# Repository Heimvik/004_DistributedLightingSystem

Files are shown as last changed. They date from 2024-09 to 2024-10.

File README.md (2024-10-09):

# Distributed LED System
## Overview
The Distributed LED System is a networked lighting project using ESP32 microcontrollers and individually addressable RGB LED strips. The system consists of a master node that processes signals and multiple slave nodes, each controlling a 1-meter LED strip. The system supports various lighting modes, including synchronization with music and spatial sound effects. When finished with the circuits to the second revision, the firmware for it will be developed in embedded C. Future progress will appear here shortly.

## Features

- **Centralized Control**: Master node coordinates LED patterns across all slave nodes.
- **Dynamic Lighting Modes**:
  - Static Colors
  - Dynamic Patterns
  - Music Synchronization
  - Spatial Sound Effects
- **Real-time Communication**: Efficiently communicates between master and slave nodes using MQTT/WebSockets.
- **User Interface**: Web-based or mobile app interface for control and configuration.

Status as of 09.10: Awaiting programmer for ESP32-WROOM32E, continuing prototyping with rpi.

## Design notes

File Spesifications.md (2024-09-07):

# Distributed LED System Specifications

## System Overview

The distributed LED system consists of several nodes, each controlling a 1-meter long LED strip. All nodes communicate with a central master node responsible for signal processing and coordinating the display patterns across all connected nodes. The system will support various lighting modes, including synchronization with music and spatial sound effects.

## System Components

- **Master Node**: Central processing unit responsible for signal processing, data transmission, and coordination of LED patterns across all slave nodes.
- **Slave Nodes**: Each node controls a 1-meter long LED strip and receives display instructions from the master node.
- **LED Strip**: Each LED strip is 1 meter long and consists of individually addressable RGB LEDs.

## Requirements

### 1. LED Strip Specifications

- **Number of LEDs per Strip**: 60 LEDs per meter (common specification for high-density strips).
- **Total Number of LEDs per Node**: 60 LEDs.

### 2. Power Consumption

- **Power Consumption per LED**: Approximately 0.24 watts (at full brightness, white).
- **Total Power Consumption per Node (White Standby)**: 
  - `60 LEDs x 0.24 watts/LED = 14.4 watts`.
  - Include an additional 10% margin for power supply inefficiencies and other components.
  - **Total Power Consumption per Node**: ~15.8 watts.

### 3. Communication Protocol

- **Master to Slave Communication**: Use a reliable communication protocol such as MQTT, HTTP, or a custom UDP/TCP protocol depending on latency and bandwidth requirements.
- **Data Transmission Rate**: Ensure data transmission supports real-time updates with minimal latency.

### 4. Lighting Modes

1. **Static Colors**: Fixed colors set by the master node.
2. **Dynamic Patterns**: Predefined or custom patterns such as waves, color shifts, and fades.
3. **Music Synchronization**:
   - **Beat Detection**: LEDs synchronize with the beats of the music.
   - **Frequency Bands**: Different frequency bands can control different LED segments or effects.
4. **Spatial Sound Effects**:
   - **Directionality**: LEDs placemnt in the room respond to distribution of sound between the channels.
   - **Sound Mapping**: Visual representation of sound sources or sound movement across the LED strips.

### 5. System Integration

- **Node Initialization**: Each node should be able to initialize and configure itself upon startup.
- **Scalability**: More nodes needs to be able to be added with no/minimum effort.

### 6. User Interface

- **Control Software**: Develop a user-friendly interface for controlling and configuring the system, including setting lighting modes and creating patterns.
- **Remote Access**: Provide options for remote control and monitoring of the system via a web interface or mobile app.

### 7. Power Supply

- **Power Supply Requirements**: Ensure each node has a stable and sufficient power supply.
- **Safety**: Include protection against overcurrent, short circuits, and overheating.

### 8. Environmental Considerations

- **Temperature Range**: Ensure the system operates reliably within the expected temperature range.
- **Humidity**: Consider humidity and potential exposure to moisture, especially for non-indoor installations.

### 9. Documentation

- **System Documentation**: Provide comprehensive documentation for setup, configuration, and troubleshooting.
- **API Documentation**: Document any APIs or communication protocols used for integration and control.

### 10. Testing and Validation

- **Functional Testing**: Validate all features and modes to ensure proper functionality.
- **Performance Testing**: Test the system's performance under various loads and conditions to ensure stability and responsiveness.

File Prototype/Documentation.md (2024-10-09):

# DSP prototype

## Server credentails
For the dsp server, the following credentials are used:
- username: heimvik
- ip: 192.168.0.134
Password is known.

## Requirements
The following is done in the setup.sh.
1. Running the requirements.

2.
. Configure curl
```cmd
curl --proto '=https' --tlsv1.2 -sSf https://sh.rustup.rs | sh
source $HOME/.cargo/env
```

3. First do:
```cmd
sudo apt update
sudo apt install build-essential libasound2-dev
git clone https://github.com/librespot-org/librespot.git
cd librespot
cargo build --release
./target/release/librespot --name "PLserver"
```
for the spotify librespot client.

4. Then install looback device:
```cmd
sudo apt install pulseaudio pavucontrol
```

5. Then install pyaudio to capture theaudio data from the virtual device:
```cmd
sudo apt install python3-pyaudio
pip3 install pyaudio
```

6. For doing real-time fft, we utilize the GPU and theGPU_FFT library on the pi.
```cmd
cd /opt/vc/src/hello_pi/hello_fft
make
sudo mknod char_dev c 100 0
```

7. Matplotlib and numpy for plotting and debugging the dsp:
```cmd
sudo apt install python3-matplotlib python3-numpy
```

8. Then set up the virtual loopback device:
```cmd
pactl load-module module-null-sink sink_name=loopback
pactl load-module module-loopback sink=loopback
```

That should be all the requirements.

Make sure the GUI is turned off, improving performance. Done by:
```cmd
sudo systemctl set-default multi-user.target
```

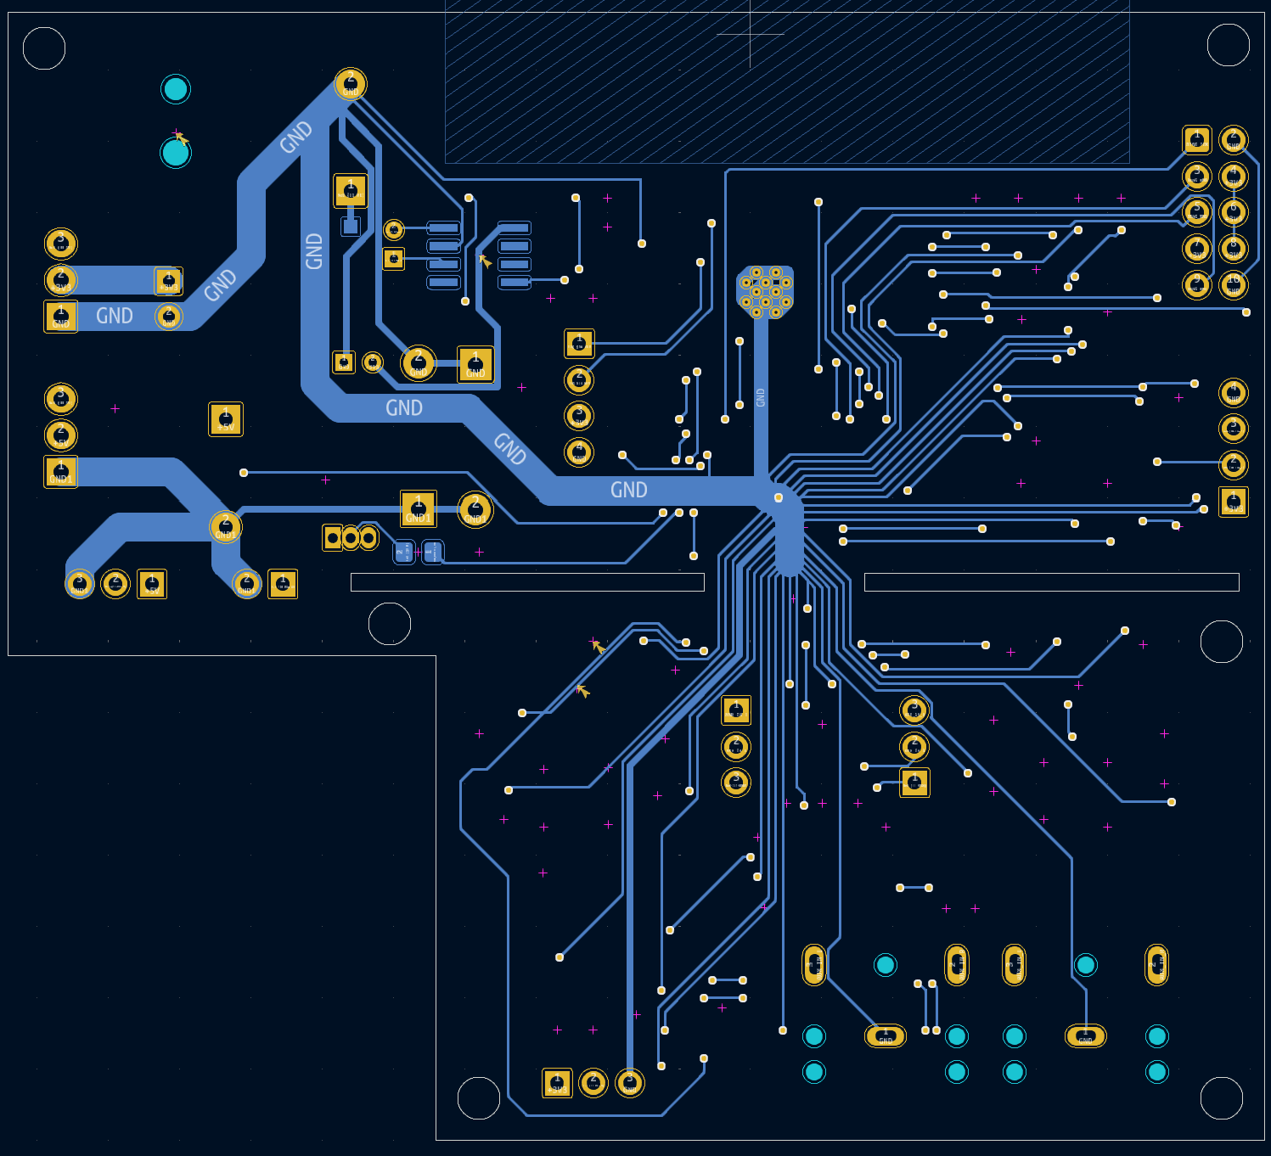
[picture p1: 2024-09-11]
Documentation/LAYER_B_CU.png

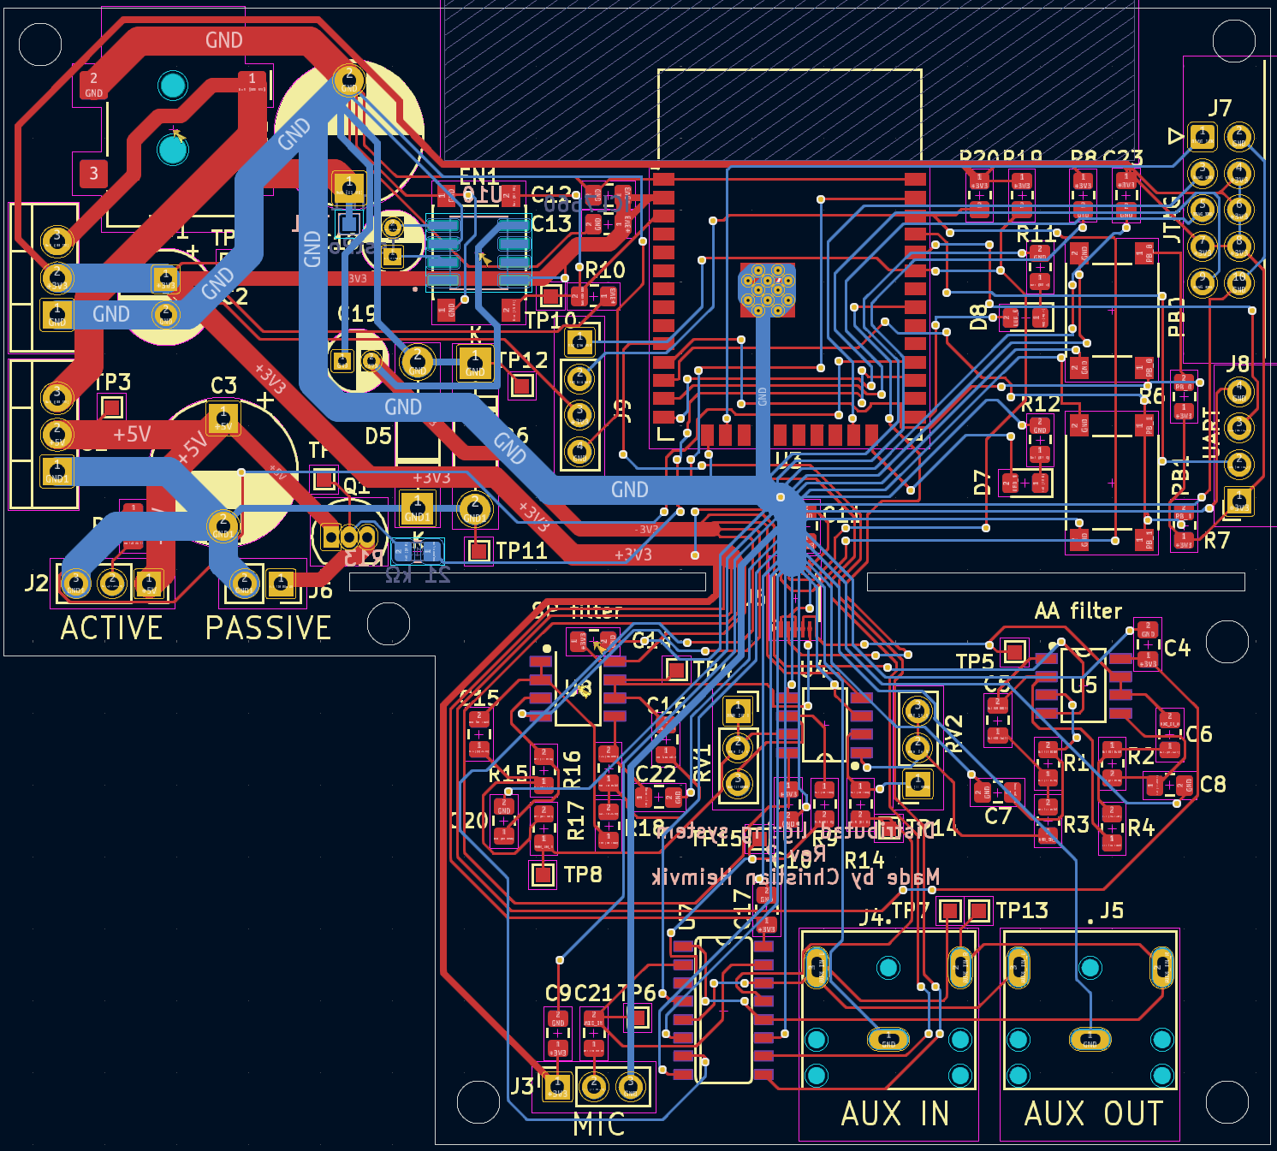
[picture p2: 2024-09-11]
Documentation/LAYER_ALL.png

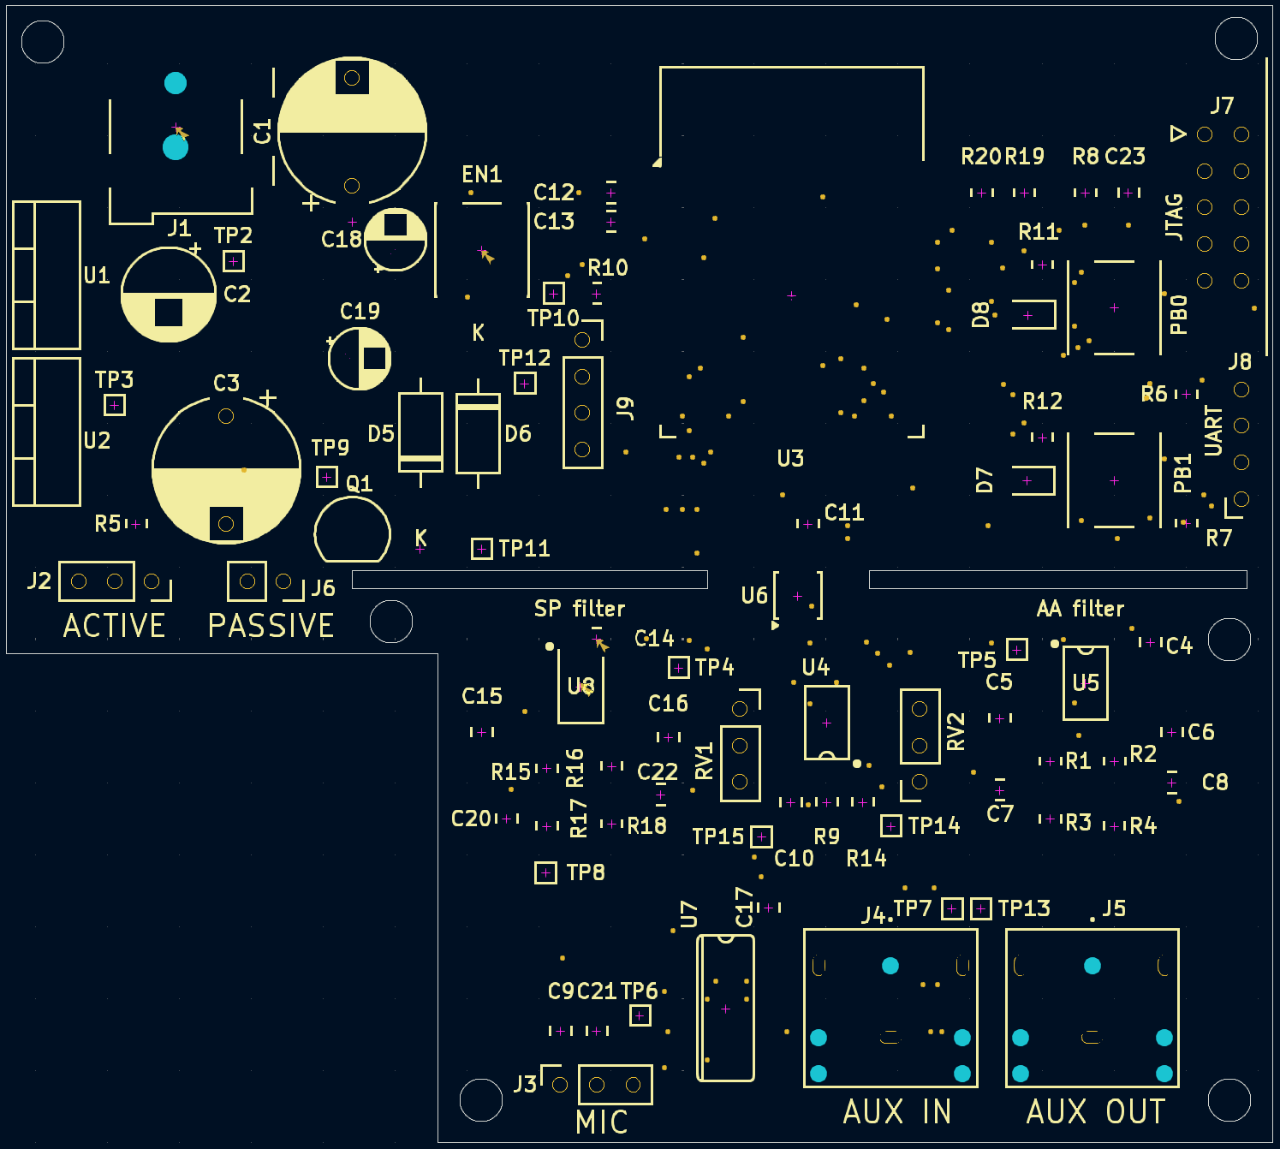
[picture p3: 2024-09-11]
Documentation/LAYER_F_SS.png

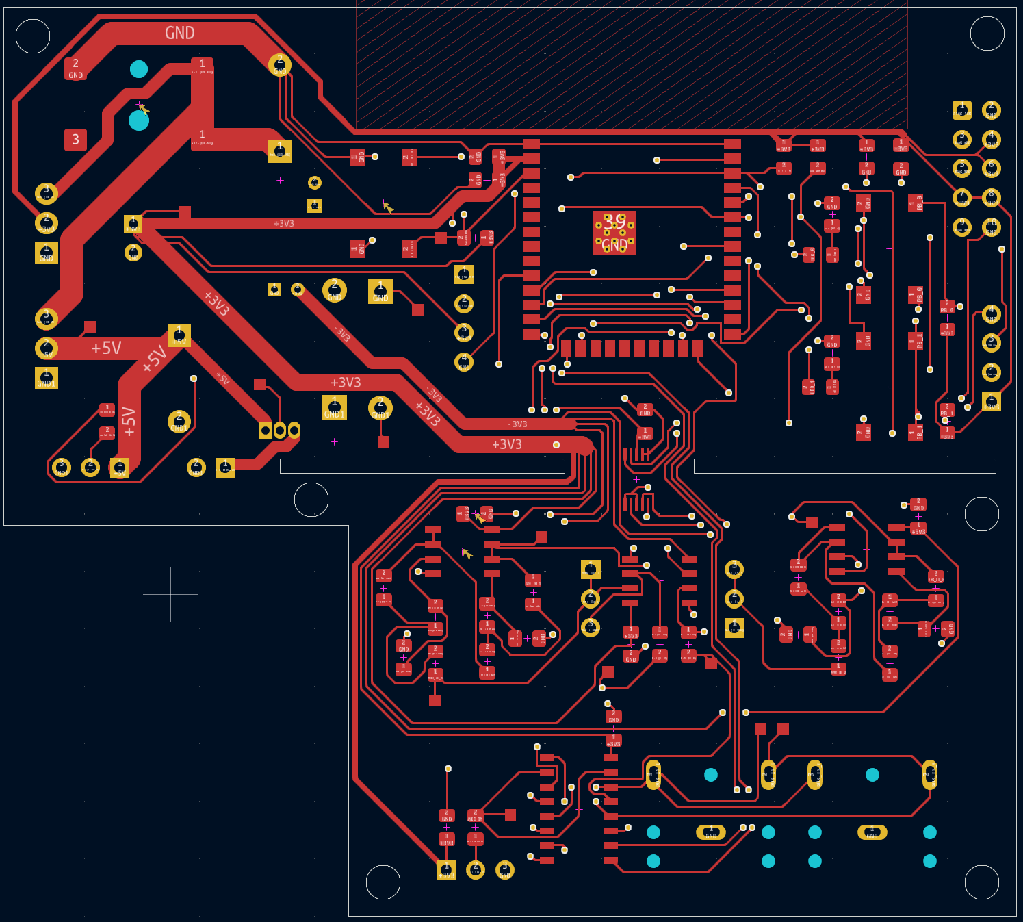
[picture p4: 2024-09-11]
Documentation/LAYER_F_CU.png

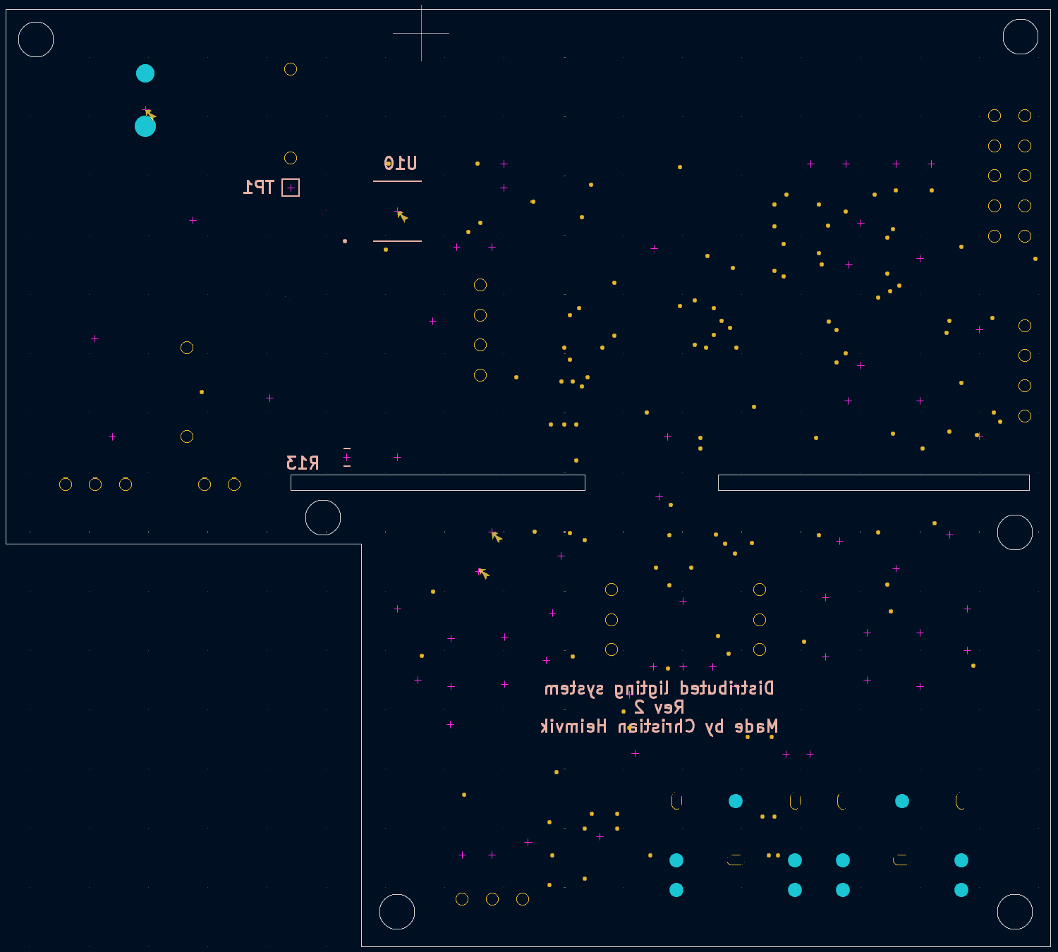
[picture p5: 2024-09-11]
Documentation/LAYER_B_SS.png

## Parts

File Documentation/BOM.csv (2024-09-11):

Reference | Value | Datasheet | Footprint | Qty | DNP
C1,C3 | 1000 uF | ~ | Capacitor_THT:CP_Radial_D10.0mm_P7.50mm | 2
C2 | 22 uF | ~ | Capacitor_THT:CP_Radial_D6.3mm_P2.50mm | 1
C4,C9,C10,C11,C13,C14,C17,C23 | 100 nF | ~ | Capacitor_SMD:C_0805_2012Metric_Pad1.18x1.45mm_HandSolder | 8
C5 | 172 nF | ~ | Capacitor_SMD:C_0805_2012Metric_Pad1.18x1.45mm_HandSolder | 1
C6 | 416 nF | ~ | Capacitor_SMD:C_0805_2012Metric_Pad1.18x1.45mm_HandSolder | 1
C7 | 147 nF | ~ | Capacitor_SMD:C_0805_2012Metric_Pad1.18x1.45mm_HandSolder | 1
C8 | 61 nF | ~ | Capacitor_SMD:C_0805_2012Metric_Pad1.18x1.45mm_HandSolder | 1
C12,C18,C19 | 10 uF | ~ | -- mixed values -- | 3
C15 | 138 nF | ~ | Capacitor_SMD:C_0805_2012Metric_Pad1.18x1.45mm_HandSolder | 1
C16 | 333 nF | ~ | Capacitor_SMD:C_0805_2012Metric_Pad1.18x1.45mm_HandSolder | 1
C20 | 117 nF | ~ | Capacitor_SMD:C_0805_2012Metric_Pad1.18x1.45mm_HandSolder | 1
C21 | 1 uF | ~ | Capacitor_SMD:C_0805_2012Metric_Pad1.18x1.45mm_HandSolder | 1
C22 | 49 nF | ~ | Capacitor_SMD:C_0805_2012Metric_Pad1.18x1.45mm_HandSolder | 1
D5,D6 | 1N5819 | http://www.vishay.com/docs/88525/1n5817.pdf | Diode_THT:D_DO-41_SOD81_P10.16mm_Horizontal | 2
D7,D8 | LED | ~ | LED_SMD:LED_0805_2012Metric_Pad1.15x1.40mm_HandSolder | 2
EN1,PB0,PB1 | SW_Push | ~ | Button_Switch_SMD:SW_Push_1P1T_NO_6x6mm_H9.5mm | 3
J1 | Barrel_Jack_MountingPin | ~ | Connector_BarrelJack:BarrelJack_Wuerth_694108106102_2.5x5.5mm | 1
J2 | WS2812B CON | ~ | Connector_PinSocket_2.54mm:PinSocket_1x03_P2.54mm_Vertical | 1
J3 | MIC CON | ~ | Connector_PinSocket_2.54mm:PinSocket_1x03_P2.54mm_Vertical | 1
J4,J5 | SJ1-3523N |  | Symbols:CUI_SJ1-3523N | 2
J6 | PASSIVE 5V LED CON | ~ | Connector_PinSocket_2.54mm:PinSocket_1x02_P2.54mm_Vertical | 1
J7 | JTAG CON | ~ | Connector_IDC:IDC-Header_2x05_P2.54mm_Horizontal | 1
J8 | UART CON | ~ | Connector_PinSocket_2.54mm:PinSocket_1x04_P2.54mm_Horizontal | 1
J9 | OLED | ~ | Connector_PinSocket_2.54mm:PinSocket_1x04_P2.54mm_Vertical | 1
Q1 | BC618 | https://diotec.com/tl_files/diotec/files/pdf/datasheets/bc337.pdf | Package_TO_SOT_THT:TO-92_Inline | 1
R1,R2,R3,R4,R6,R7,R8,R10 | 10 kΩ | ~ | Resistor_SMD:R_0805_2012Metric_Pad1.20x1.40mm_HandSolder | 8
R5 | 330 Ω | ~ | Resistor_SMD:R_0805_2012Metric_Pad1.20x1.40mm_HandSolder | 1
R9,R14,R15,R16,R17,R18 | 1 kΩ | ~ | Resistor_SMD:R_0805_2012Metric_Pad1.20x1.40mm_HandSolder | 6
R11,R12 | 33 Ω | ~ | Resistor_SMD:R_0805_2012Metric_Pad1.20x1.40mm_HandSolder | 2
R13 | 21 kΩ | ~ | Resistor_SMD:R_0805_2012Metric_Pad1.20x1.40mm_HandSolder | 1
R19,R20 | 4.7 kΩ | ~ | Resistor_SMD:R_0805_2012Metric_Pad1.20x1.40mm_HandSolder | 2
RV1,RV2 | 0<R<10 kΩ | ~ | Connector_PinSocket_2.54mm:PinSocket_1x03_P2.54mm_Vertical | 2
TP1,TP2,TP3,TP4,TP5,TP6,TP7,TP8,TP9,TP10,TP11,TP12,TP13,TP14,TP15 | TestPoint | ~ | TestPoint:TestPoint_Pad_1.0x1.0mm | 15
U1 | LM1117T-3.3 | http://www.ti.com/lit/ds/symlink/lm1117.pdf | Package_TO_SOT_THT:TO-220-3_Vertical | 1
U2 | LT1084-5.0 | https://www.analog.com/media/en/technical-documentation/data-sheets/1083ffe.pdf | Package_TO_SOT_THT:TO-220-3_Vertical | 1
U3 | ESP32-WROOM-32E | https://www.espressif.com/sites/default/files/documentation/esp32-wroom-32e_esp32-wroom-32ue_datasheet_en.pdf | RF_Module:ESP32-WROOM-32D | 1
U4,U5,U8 | LF353N |  | USR_LIB:LF353 | 3
U6 | ADS1015IDGS | http://www.ti.com/lit/ds/symlink/ads1015.pdf | Package_SO:TSSOP-10_3x3mm_P0.5mm | 1
U7 | 74HC4052 |  | USR_LIB:MUX | 1
U10 | ICL7660 | http://datasheets.maximintegrated.com/en/ds/ICL7660-MAX1044.pdf | USR_LIB:ICL7660 | 1

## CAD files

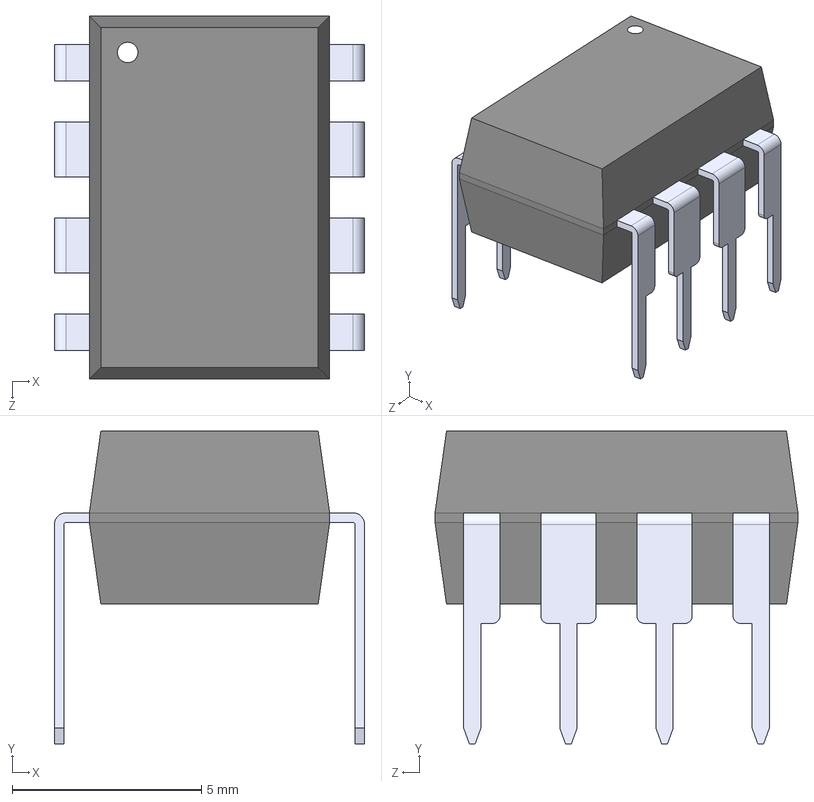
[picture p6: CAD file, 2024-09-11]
Rev2/Symbols/LF353N.step
8.19 x 8.26 x 9.59 mm

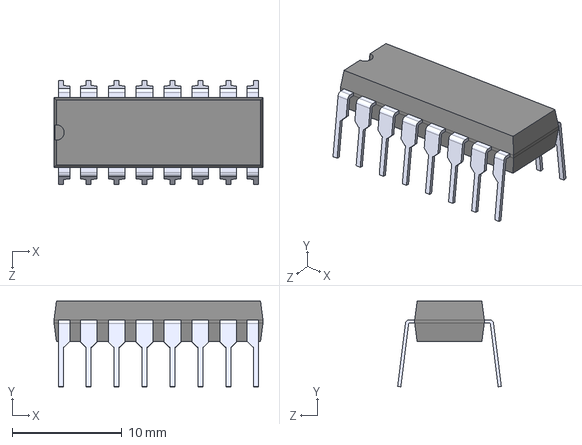
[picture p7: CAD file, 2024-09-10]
Rev2/Symbols/74HC4052.step
19.0 x 7.80 x 9.44 mm

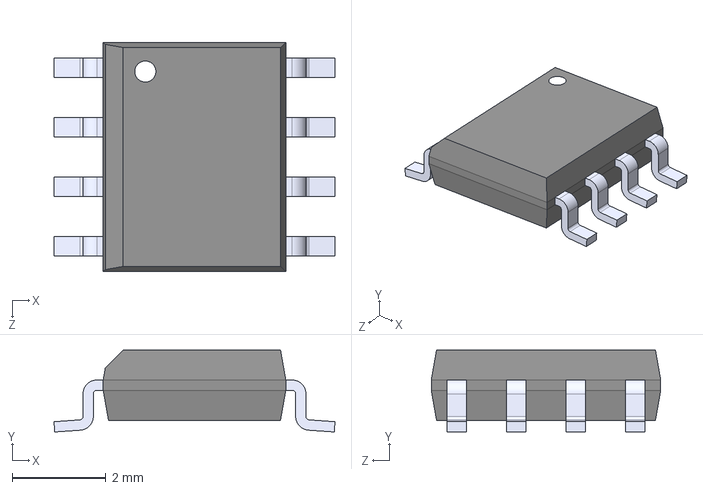
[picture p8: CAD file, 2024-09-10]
Rev2/Symbols/ICL7660CSA.step
6.00 x 1.75 x 4.90 mm

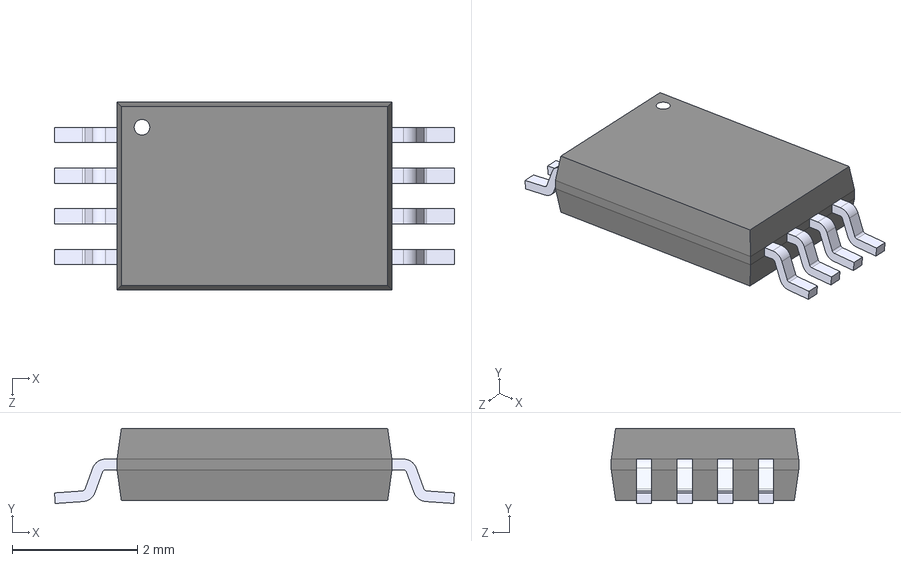
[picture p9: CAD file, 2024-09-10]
Rev2/Symbols/MCP3202-CI_ST.step
6.40 x 1.20 x 3.00 mm

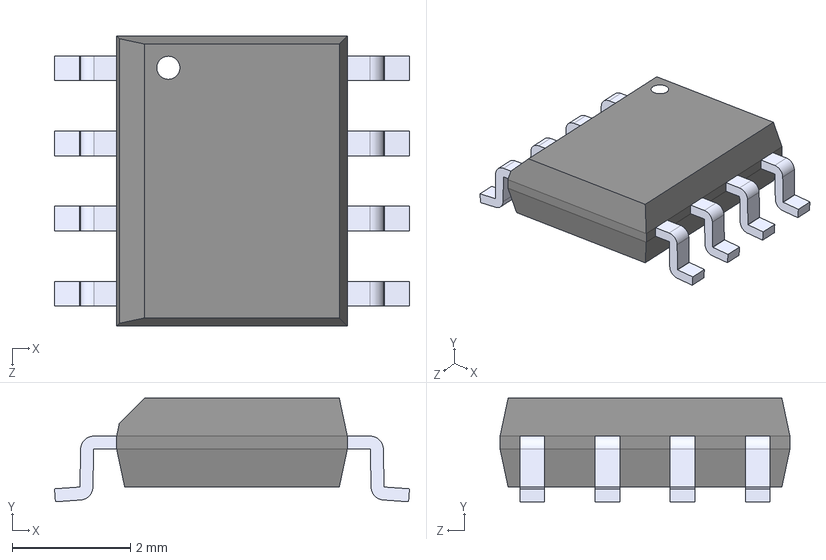
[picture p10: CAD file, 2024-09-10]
Rev2/Symbols/LF353.step
6.00 x 1.75 x 4.90 mm

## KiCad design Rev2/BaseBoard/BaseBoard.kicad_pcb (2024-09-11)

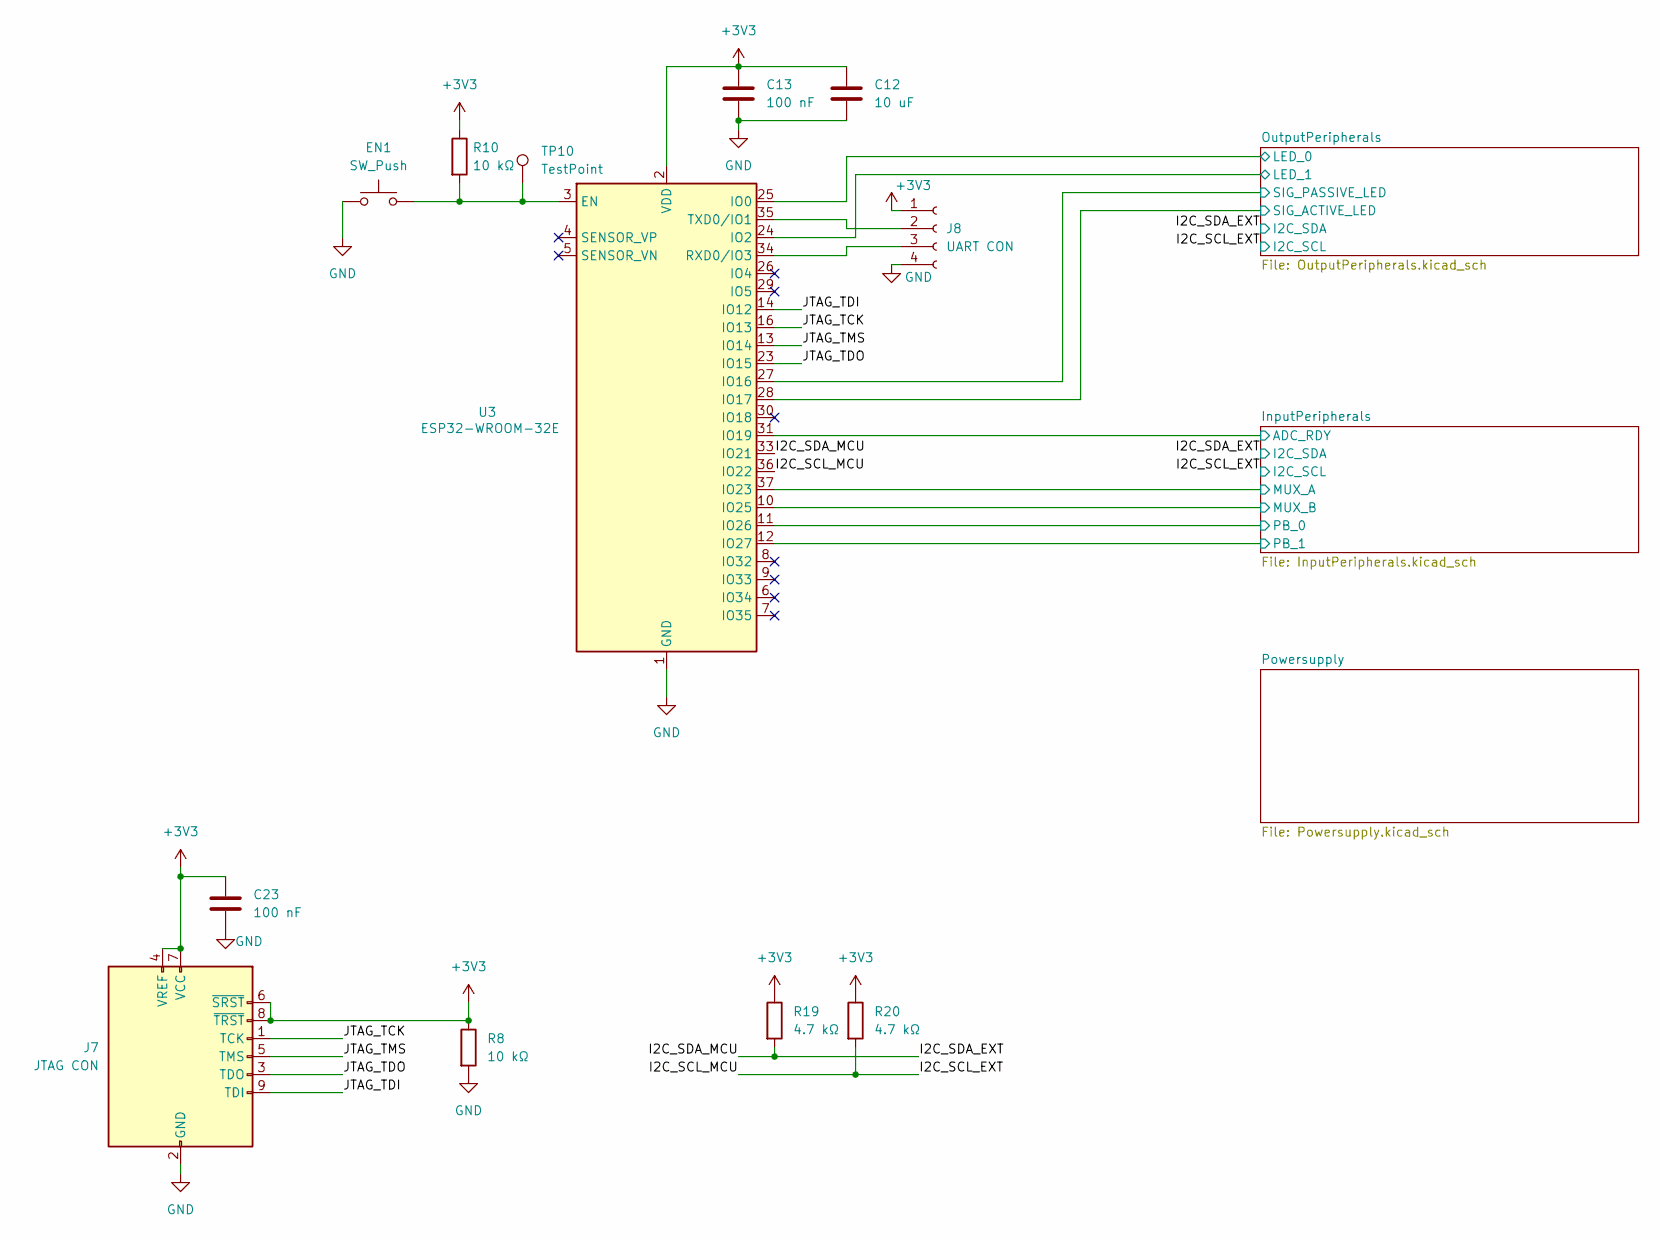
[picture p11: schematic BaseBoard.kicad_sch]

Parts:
C12: 10 uF; C_0805_2012Metric_Pad1.18x1.45mm_HandSolder
C13, C23: 100 nF; C_0805_2012Metric_Pad1.18x1.45mm_HandSolder
EN1: SW_Push; SW_Push_1P1T_NO_6x6mm_H9.5mm
J7: JTAG CON; IDC-Header_2x05_P2.54mm_Horizontal
J8: UART CON; PinSocket_1x04_P2.54mm_Horizontal
R8, R10: 10 kΩ; R_0805_2012Metric_Pad1.20x1.40mm_HandSolder
R19, R20: 4.7 kΩ; R_0805_2012Metric_Pad1.20x1.40mm_HandSolder
TP10: TestPoint; TestPoint_Pad_1.0x1.0mm
U3: ESP32-WROOM-32E; ESP32-WROOM-32D

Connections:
+3V3: C12.1, C13.1, C23.1, J7.4 (VREF), J7.6 (~SRST), J7.7 (VCC), J7.8 (~TRST), J8.1, R8.1, R10.1, R19.1, R20.1, U3.2 (VDD); also elsewhere on the board
/I2C_SCL_EXT: R20.2, U3.36 (IO22); also elsewhere on the board
/I2C_SDA_EXT: R19.2, U3.33 (IO21); also elsewhere on the board
/InputPeripherals/ADC_RDY: U3.31 (IO19); also elsewhere on the board
/InputPeripherals/MUX_A: U3.37 (IO23); also elsewhere on the board
/InputPeripherals/MUX_B: U3.10 (IO25); also elsewhere on the board
/InputPeripherals/PB_0: U3.11 (IO26); also elsewhere on the board
/InputPeripherals/PB_1: U3.12 (IO27); also elsewhere on the board
/JTAG_TCK: J7.1 (TCK), U3.16 (IO13)
/JTAG_TDI: J7.9 (TDI), U3.14 (IO12)
/JTAG_TDO: J7.3 (TDO), U3.23 (IO15)
/JTAG_TMS: J7.5 (TMS), U3.13 (IO14)
/OutputPeripherals/LED_0: U3.25 (IO0); also elsewhere on the board
/OutputPeripherals/LED_1: U3.24 (IO2); also elsewhere on the board
/OutputPeripherals/SIG_ACTIVE_LED: U3.28 (IO17); also elsewhere on the board
/OutputPeripherals/SIG_PASSIVE_LED: U3.27 (IO16); also elsewhere on the board
GND: C12.2, C13.2, C23.2, EN1.1, J7.2 (GND), J7.10 (GND), J8.4, R8.2, U3.1 (GND), U3.15 (GND), U3.38 (GND), U3.39 (GND); also elsewhere on the board
unnamed: J8.2, U3.35 (TXD0/IO1)
unnamed: J8.3, U3.34 (RXD0/IO3)
unnamed: EN1.2, R10.2, TP10.1, U3.3 (EN)

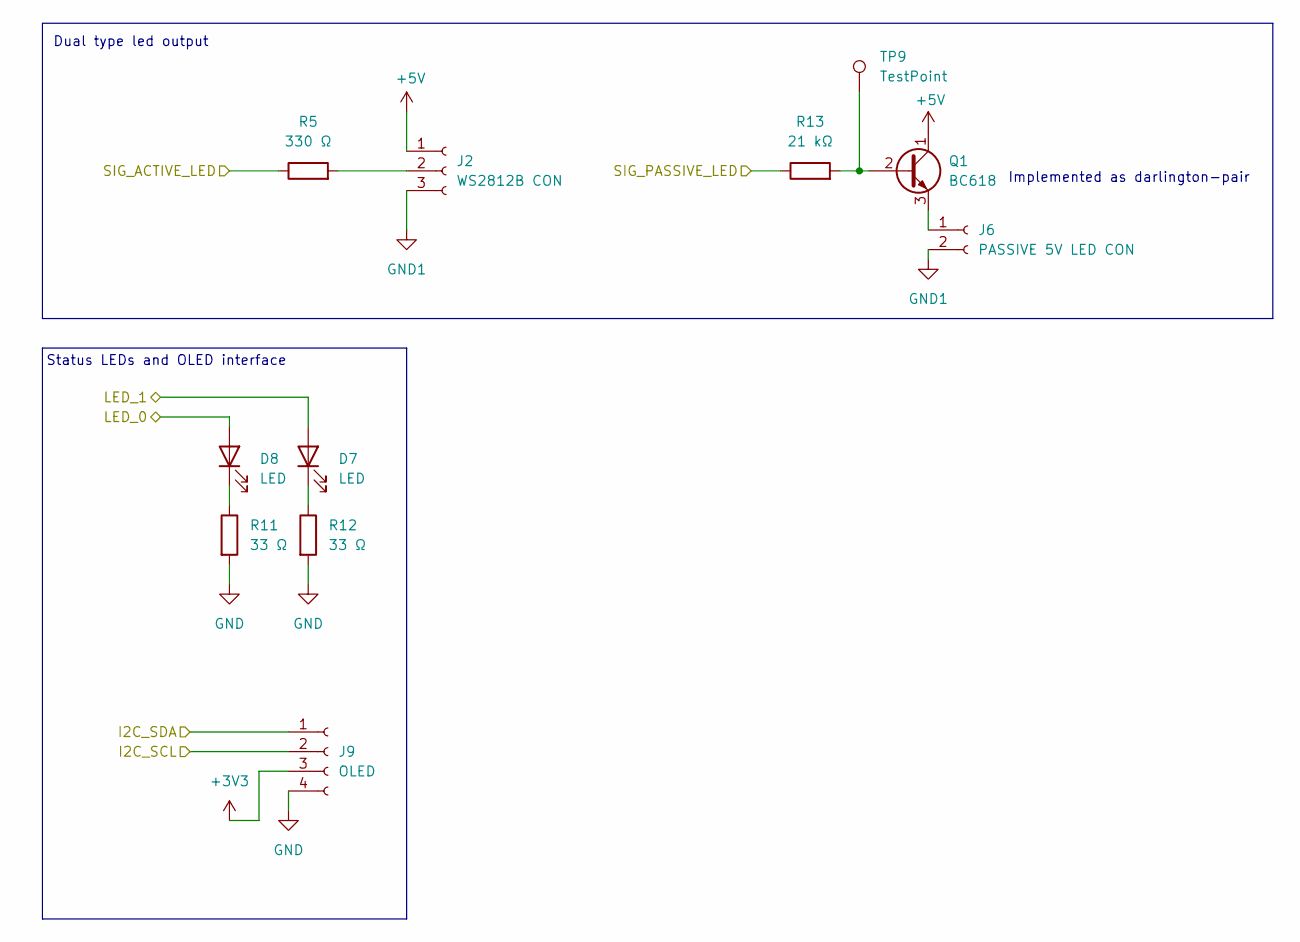
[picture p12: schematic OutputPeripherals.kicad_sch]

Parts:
D7, D8: LED; LED_0805_2012Metric_Pad1.15x1.40mm_HandSolder
J2: WS2812B CON; PinSocket_1x03_P2.54mm_Vertical
J6: PASSIVE 5V LED CON; PinSocket_1x02_P2.54mm_Vertical
J9: OLED; PinSocket_1x04_P2.54mm_Vertical
Q1: BC618; TO-92_Inline
R5: 330 Ω; R_0805_2012Metric_Pad1.20x1.40mm_HandSolder
R11, R12: 33 Ω; R_0805_2012Metric_Pad1.20x1.40mm_HandSolder
R13: 21 kΩ; R_0805_2012Metric_Pad1.20x1.40mm_HandSolder
TP9: TestPoint; TestPoint_Pad_1.0x1.0mm

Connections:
+3V3: J9.3; also elsewhere on the board
+5V: J2.1, Q1.1 (C); also elsewhere on the board
/I2C_SCL_EXT: J9.2; also elsewhere on the board
/I2C_SDA_EXT: J9.1; also elsewhere on the board
/OutputPeripherals/LED_0: D8.2 (A); also elsewhere on the board
/OutputPeripherals/LED_1: D7.2 (A); also elsewhere on the board
/OutputPeripherals/SIG_ACTIVE_LED: R5.1; also elsewhere on the board
/OutputPeripherals/SIG_PASSIVE_LED: R13.1; also elsewhere on the board
GND: J9.4, R11.2, R12.2; also elsewhere on the board
GND1: J2.3, J6.2; also elsewhere on the board
unnamed: D7.1 (K), R12.1
unnamed: D8.1 (K), R11.1
unnamed: J2.2, R5.2
unnamed: J6.1, Q1.3 (E)
unnamed: Q1.2 (B), R13.2, TP9.1

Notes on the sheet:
Dual type led output
Implemented as darlington-pair
Status LEDs and OLED interface

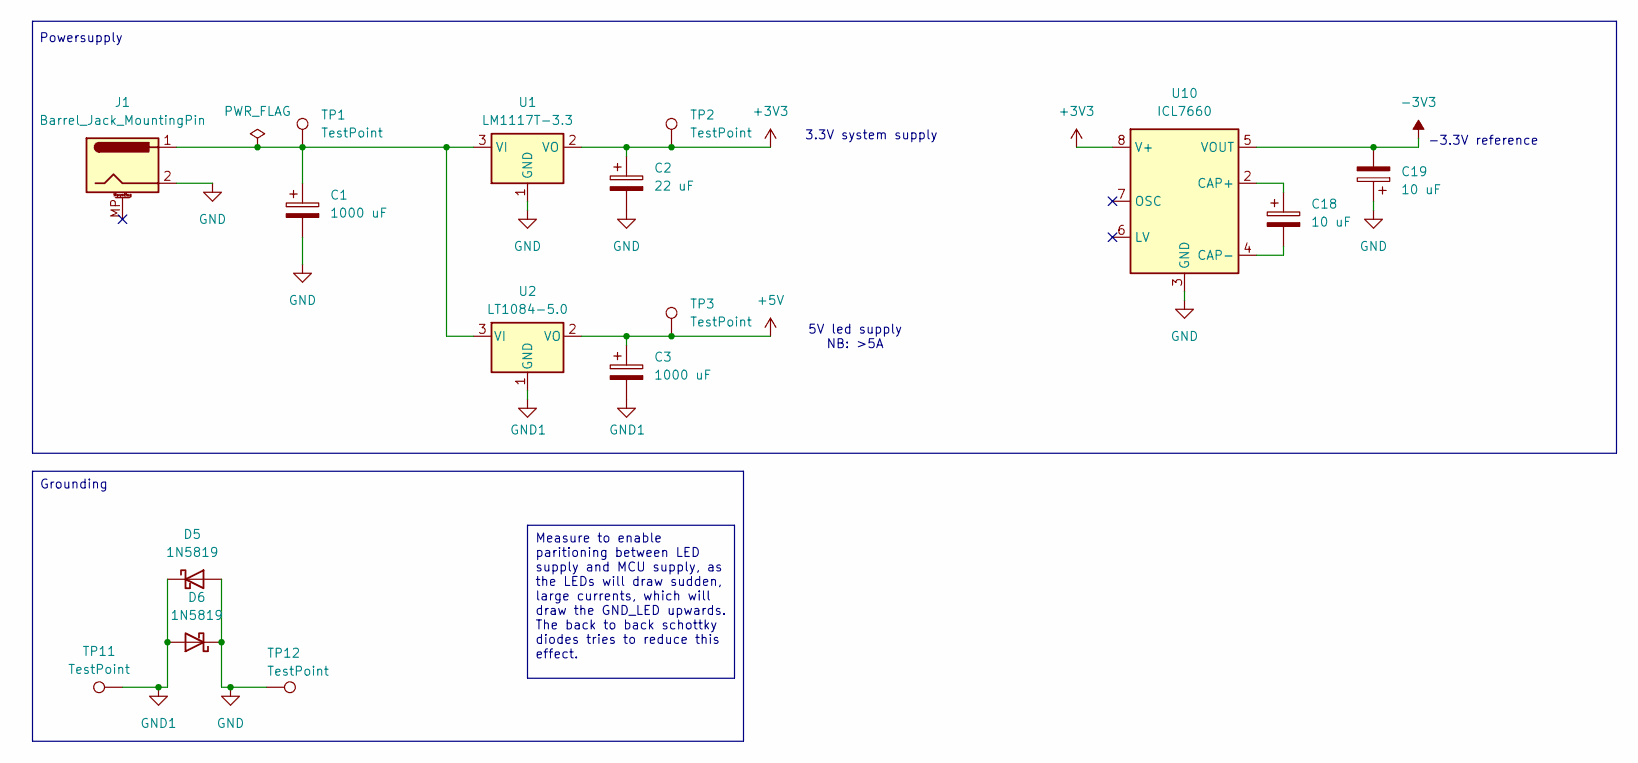
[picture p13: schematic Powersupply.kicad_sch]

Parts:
C1, C3: 1000 uF; CP_Radial_D10.0mm_P7.50mm
C2: 22 uF; CP_Radial_D6.3mm_P2.50mm
C18, C19: 10 uF; CP_Radial_D4.0mm_P2.00mm
D5, D6: 1N5819; D_DO-41_SOD81_P10.16mm_Horizontal
J1: Barrel_Jack_MountingPin; BarrelJack_Wuerth_694108106102_2.5x5.5mm
TP1, TP2, TP3, TP11, TP12: TestPoint; TestPoint_Pad_1.0x1.0mm
U1: LM1117T-3.3; TO-220-3_Vertical
U2: LT1084-5.0; TO-220-3_Vertical
U10: ICL7660

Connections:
+3V3: C2.1, TP2.1, U1.2 (VO), U10.8 (V+); also elsewhere on the board
+5V: C3.1, TP3.1, U2.2 (VO); also elsewhere on the board
-3V3: C19.2, U10.5 (VOUT); also elsewhere on the board
GND: C1.2, C2.2, C19.1, D5.2 (A), D6.1 (K), J1.2, TP12.1, U1.1 (GND), U10.3 (GND); also elsewhere on the board
GND1: C3.2, D5.1 (K), D6.2 (A), TP11.1, U2.1 (GND); also elsewhere on the board
unnamed: C1.1, J1.1, TP1.1, U1.3 (VI), U2.3 (VI)
unnamed: C18.1, U10.2 (CAP+)
unnamed: C18.2, U10.4 (CAP-)

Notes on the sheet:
Measure to enable paritioning between LED supply and MCU supply, as the LEDs will draw sudden, large currents, which will draw the GND_LED upwards. The back to back schottky diodes tries to reduce this effect.
3.3V system supply
Grounding
Powersupply
-3.3V reference
5V led supply NB: >5A

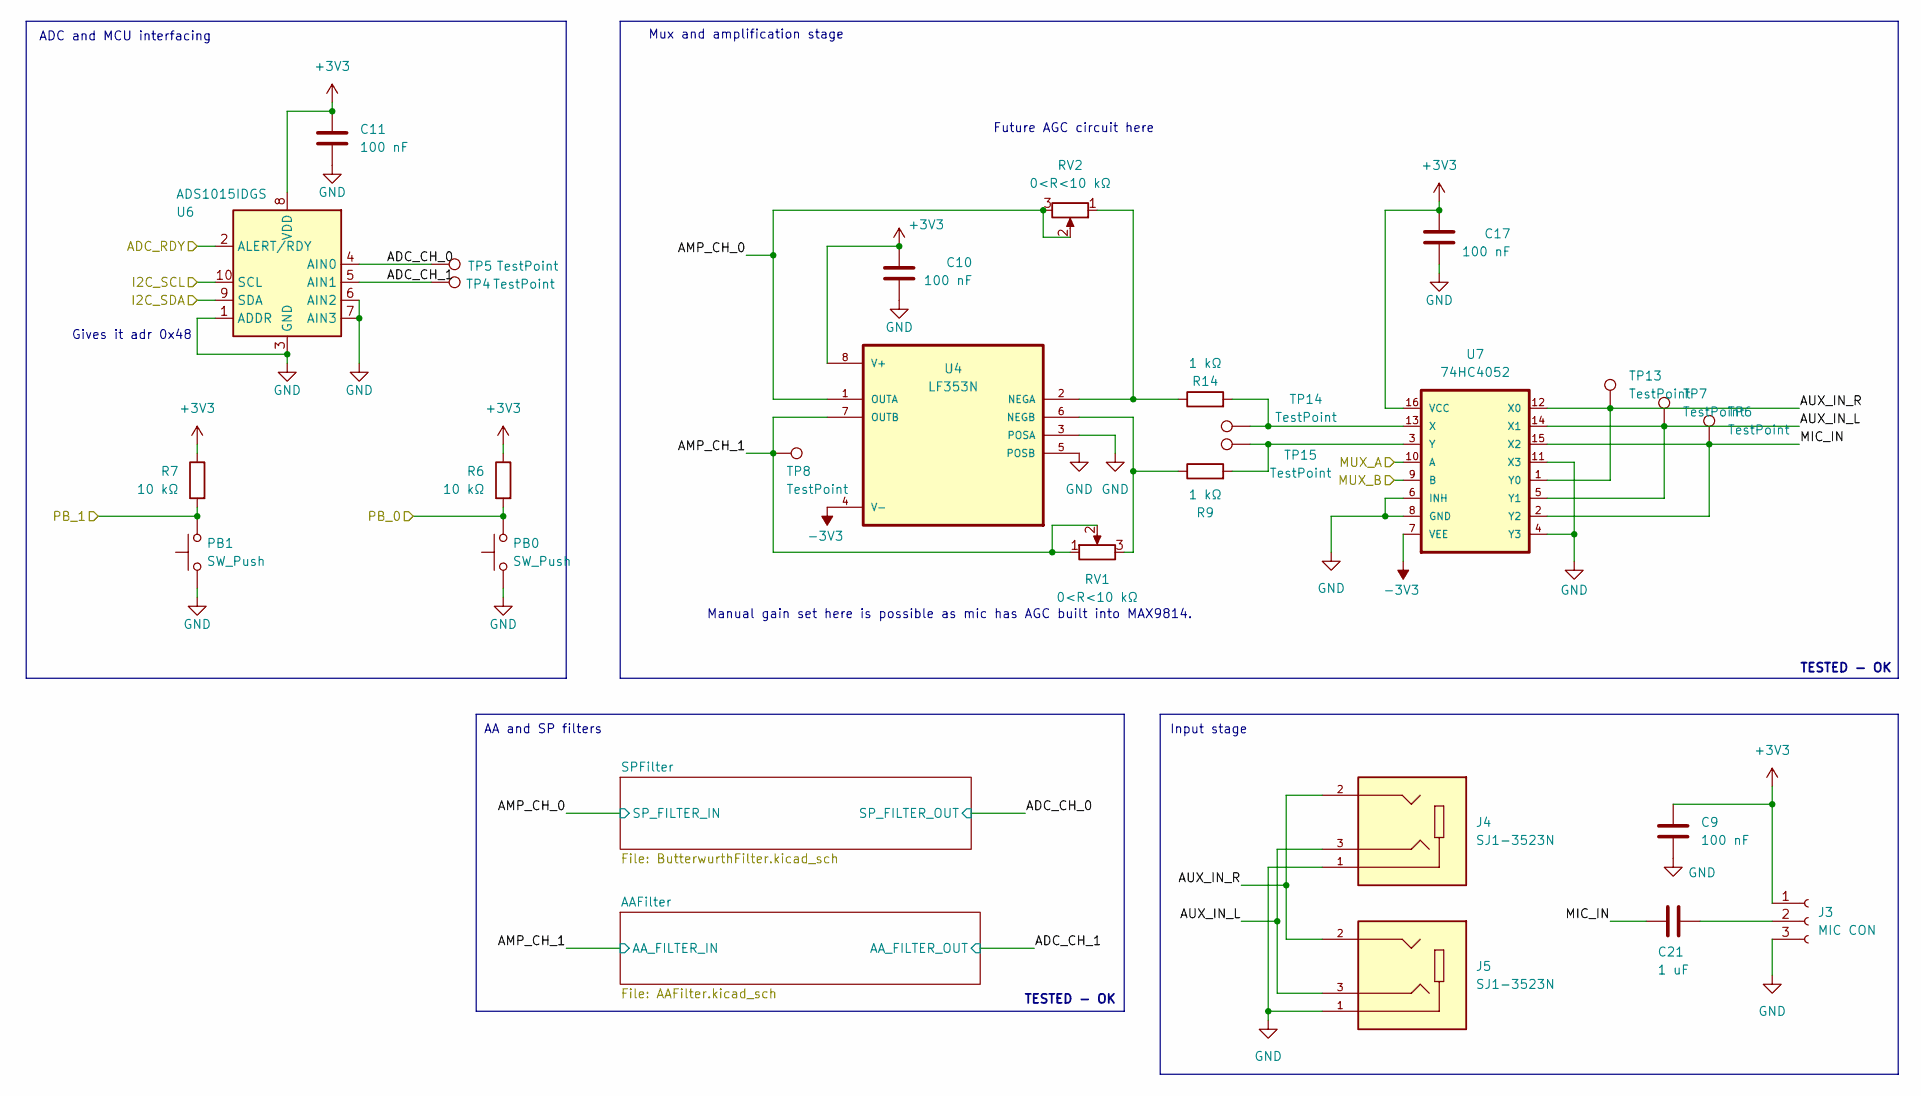
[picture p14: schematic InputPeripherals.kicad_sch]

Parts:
C9, C10, C11, C17: 100 nF; C_0805_2012Metric_Pad1.18x1.45mm_HandSolder
C21: 1 uF; C_0805_2012Metric_Pad1.18x1.45mm_HandSolder
J3: MIC CON; PinSocket_1x03_P2.54mm_Vertical
J4, J5: SJ1-3523N; CUI_SJ1-3523N; PARTREV 1.05
PB0, PB1: SW_Push; SW_Push_1P1T_NO_6x6mm_H9.5mm
R6, R7: 10 kΩ; R_0805_2012Metric_Pad1.20x1.40mm_HandSolder
R9, R14: 1 kΩ; R_0805_2012Metric_Pad1.20x1.40mm_HandSolder
RV1, RV2: 0<R<10 kΩ; PinSocket_1x03_P2.54mm_Vertical
TP4, TP5, TP6, TP7, TP8, TP13, TP14, TP15: TestPoint; TestPoint_Pad_1.0x1.0mm
U4: LF353N; LF353
U6: ADS1015IDGS; TSSOP-10_3x3mm_P0.5mm
U7: 74HC4052; MUX

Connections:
+3V3: C9.1, C10.1, C11.1, C17.1, J3.1, R6.1, R7.1, U4.8 (V+), U6.8 (VDD), U7.16 (VCC); also elsewhere on the board
-3V3: U4.4 (V-), U7.7 (VEE); also elsewhere on the board
/I2C_SCL_EXT: U6.10 (SCL); also elsewhere on the board
/I2C_SDA_EXT: U6.9 (SDA); also elsewhere on the board
/InputPeripherals/ADC_CH_0: TP5.1, U6.4 (AIN0); also elsewhere on the board
/InputPeripherals/ADC_CH_1: TP4.1, U6.5 (AIN1); also elsewhere on the board
/InputPeripherals/ADC_RDY: U6.2 (ALERT/RDY); also elsewhere on the board
/InputPeripherals/AMP_CH_0: RV2.2, RV2.3, U4.1 (OUTA); also elsewhere on the board
/InputPeripherals/AMP_CH_1: RV1.1, RV1.2, TP8.1, U4.7 (OUTB); also elsewhere on the board
/InputPeripherals/AUX_IN_L: J4.3, J5.3, TP7.1, U7.5 (Y1), U7.14 (X1)
/InputPeripherals/AUX_IN_R: J4.2, J5.2, TP13.1, U7.1 (Y0), U7.12 (X0)
/InputPeripherals/MIC_IN: C21.2, TP6.1, U7.2 (Y2), U7.15 (X2)
/InputPeripherals/MUX_A: U7.10 (A); also elsewhere on the board
/InputPeripherals/MUX_B: U7.9 (B); also elsewhere on the board
/InputPeripherals/PB_0: PB0.1, R6.2; also elsewhere on the board
/InputPeripherals/PB_1: PB1.1, R7.2; also elsewhere on the board
GND: C9.2, C10.2, C11.2, C17.2, J3.3, J4.1, J5.1, PB0.2, PB1.2, U4.3 (POSA), U4.5 (POSB), U6.1 (ADDR), U6.3 (GND), U6.6 (AIN2), U6.7 (AIN3), U7.4 (Y3), U7.6 (INH), U7.8 (GND), U7.11 (X3); also elsewhere on the board
unnamed: C21.1, J3.2
unnamed: R14.1, RV2.1, U4.2 (NEGA)
unnamed: R9.1, RV1.3, U4.6 (NEGB)
unnamed: R14.2, TP14.1, U7.13 (X)
unnamed: R9.2, TP15.1, U7.3 (Y)

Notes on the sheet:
AA and SP filters
TESTED - OK
Gives it adr 0x48
Future AGC circuit here
Input stage
Manual gain set here is possible as mic has AGC built into MAX9814.
Mux and amplification stage
ADC and MCU interfacing

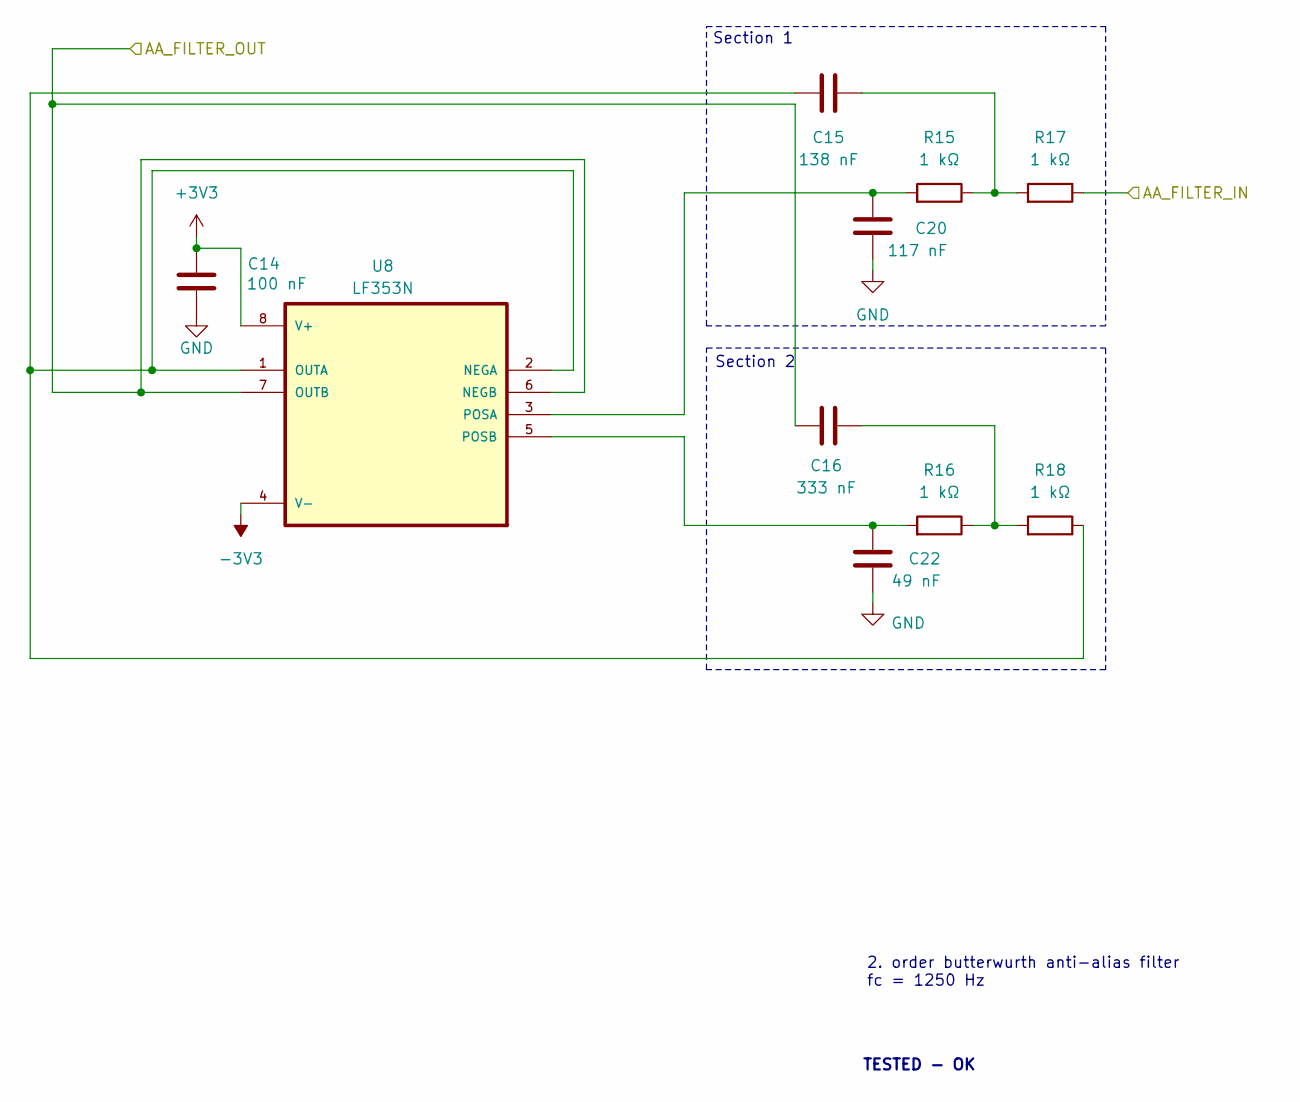
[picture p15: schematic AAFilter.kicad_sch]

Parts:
C14: 100 nF; C_0805_2012Metric_Pad1.18x1.45mm_HandSolder
C15: 138 nF; C_0805_2012Metric_Pad1.18x1.45mm_HandSolder
C16: 333 nF; C_0805_2012Metric_Pad1.18x1.45mm_HandSolder
C20: 117 nF; C_0805_2012Metric_Pad1.18x1.45mm_HandSolder
C22: 49 nF; C_0805_2012Metric_Pad1.18x1.45mm_HandSolder
R15, R16, R17, R18: 1 kΩ; R_0805_2012Metric_Pad1.20x1.40mm_HandSolder
U8: LF353N; LF353

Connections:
+3V3: C14.1, U8.8 (V+); also elsewhere on the board
-3V3: U8.4 (V-); also elsewhere on the board
/InputPeripherals/ADC_CH_1: C16.2, U8.6 (NEGB), U8.7 (OUTB); also elsewhere on the board
/InputPeripherals/AMP_CH_1: R17.1; also elsewhere on the board
GND: C14.2, C20.2, C22.2; also elsewhere on the board
unnamed: C15.1, R15.1, R17.2
unnamed: C16.1, R16.1, R18.2
unnamed: C15.2, R18.1, U8.1 (OUTA), U8.2 (NEGA)
unnamed: C20.1, R15.2, U8.3 (POSA)
unnamed: C22.1, R16.2, U8.5 (POSB)

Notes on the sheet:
TESTED - OK
2. order butterwurth anti-alias filter fc = 1250 Hz
Section 1
Section 2

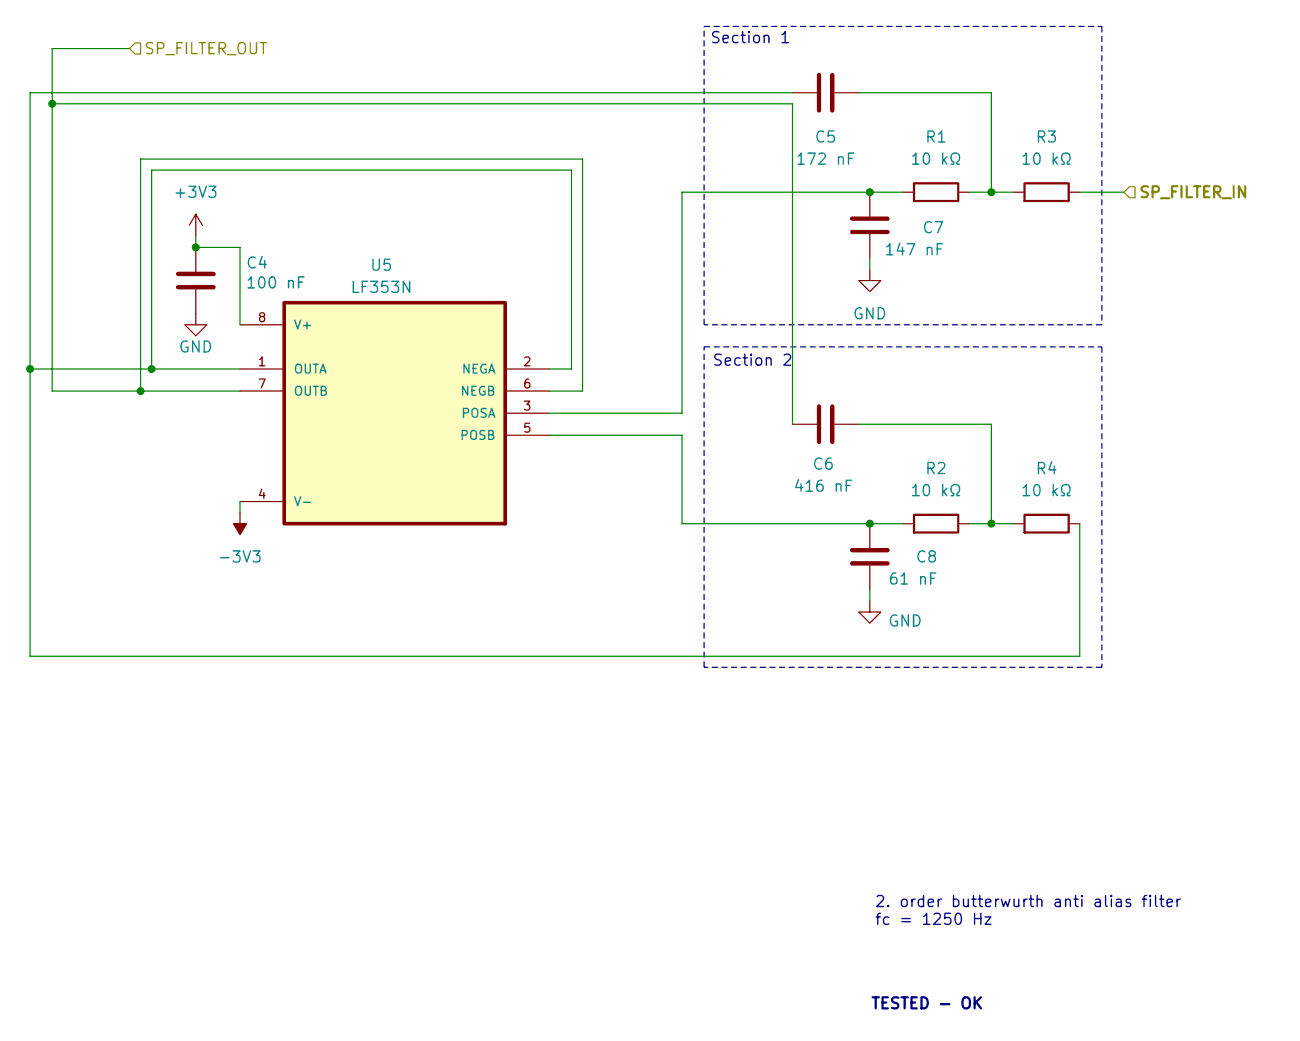
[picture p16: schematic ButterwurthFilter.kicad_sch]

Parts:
C4: 100 nF; C_0805_2012Metric_Pad1.18x1.45mm_HandSolder
C5: 172 nF; C_0805_2012Metric_Pad1.18x1.45mm_HandSolder
C6: 416 nF; C_0805_2012Metric_Pad1.18x1.45mm_HandSolder
C7: 147 nF; C_0805_2012Metric_Pad1.18x1.45mm_HandSolder
C8: 61 nF; C_0805_2012Metric_Pad1.18x1.45mm_HandSolder
R1, R2, R3, R4: 10 kΩ; R_0805_2012Metric_Pad1.20x1.40mm_HandSolder
U5: LF353N; LF353

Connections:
+3V3: C4.1, U5.8 (V+); also elsewhere on the board
-3V3: U5.4 (V-); also elsewhere on the board
/InputPeripherals/ADC_CH_0: C6.2, U5.6 (NEGB), U5.7 (OUTB); also elsewhere on the board
/InputPeripherals/AMP_CH_0: R3.1; also elsewhere on the board
GND: C4.2, C7.2, C8.2; also elsewhere on the board
unnamed: C5.1, R1.1, R3.2
unnamed: C6.1, R2.1, R4.2
unnamed: C5.2, R4.1, U5.1 (OUTA), U5.2 (NEGA)
unnamed: C7.1, R1.2, U5.3 (POSA)
unnamed: C8.1, R2.2, U5.5 (POSB)

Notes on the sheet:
TESTED - OK
2. order butterwurth anti alias filter fc = 1250 Hz
Section 2
Section 1

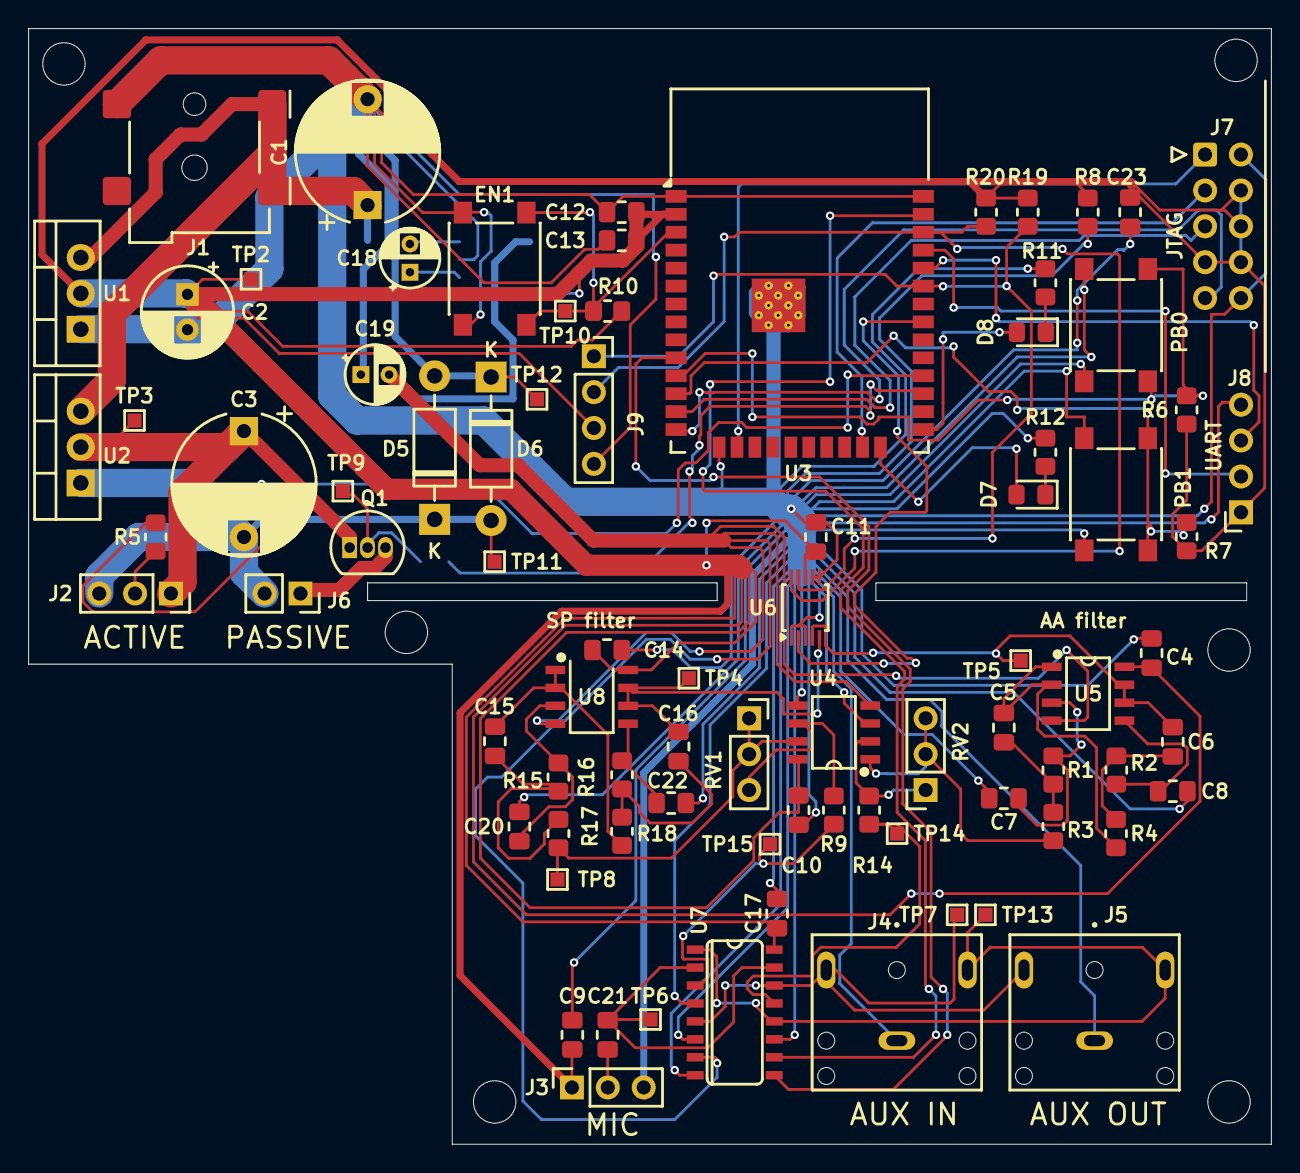
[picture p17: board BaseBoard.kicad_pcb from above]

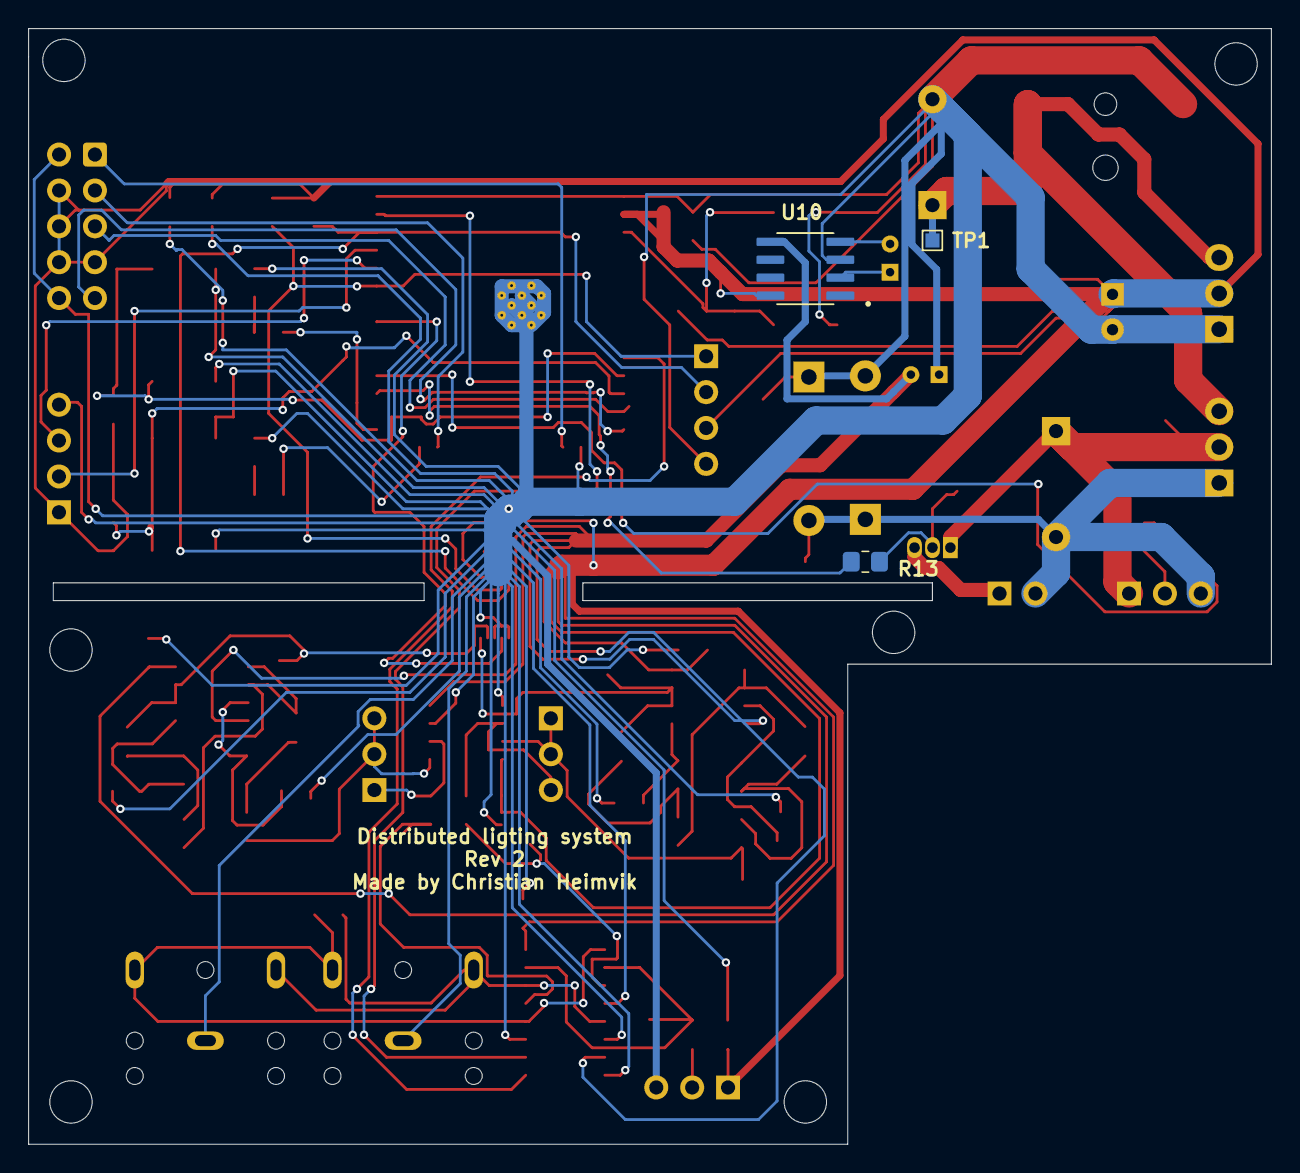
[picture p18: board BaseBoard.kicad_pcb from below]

Board: 2 copper layers, 88.0 x 79.0 mm, 86 parts (3 on the bottom side), 53 nets.

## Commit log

2024-09-07 Added ADC an peripherals
    [BaseBoard.kicad_pcb, BaseBoard.kicad_sch, InputPeripherals.kicad_sch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]
2024-09-07 Added Testpoints, UART and JTAG
    [BaseBoard.kicad_sch, InputPeripherals.kicad_sch, OutputPeripherals.kicad_sch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]
2024-09-10 Finished placement, routing remains
    [74HC4052.step, AAFilter.kicad_sch, BaseBoard.kicad_pcb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]
2024-09-11 Finished rev 2
    [BaseBoard-B_Cu.gbl, BaseBoard-B_Mask.gbs, BaseBoard-B_Paste.gbp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]
2024-09-11 Images and BOM
    [BOM.csv]
2024-10-09 Working on capturing device
